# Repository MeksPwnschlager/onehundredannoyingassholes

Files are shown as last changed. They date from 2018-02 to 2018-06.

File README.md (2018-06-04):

# onehundredannoyingassholes 

Piezo Buzzer Throwies which buzz every 15-30 minutes and should last months.

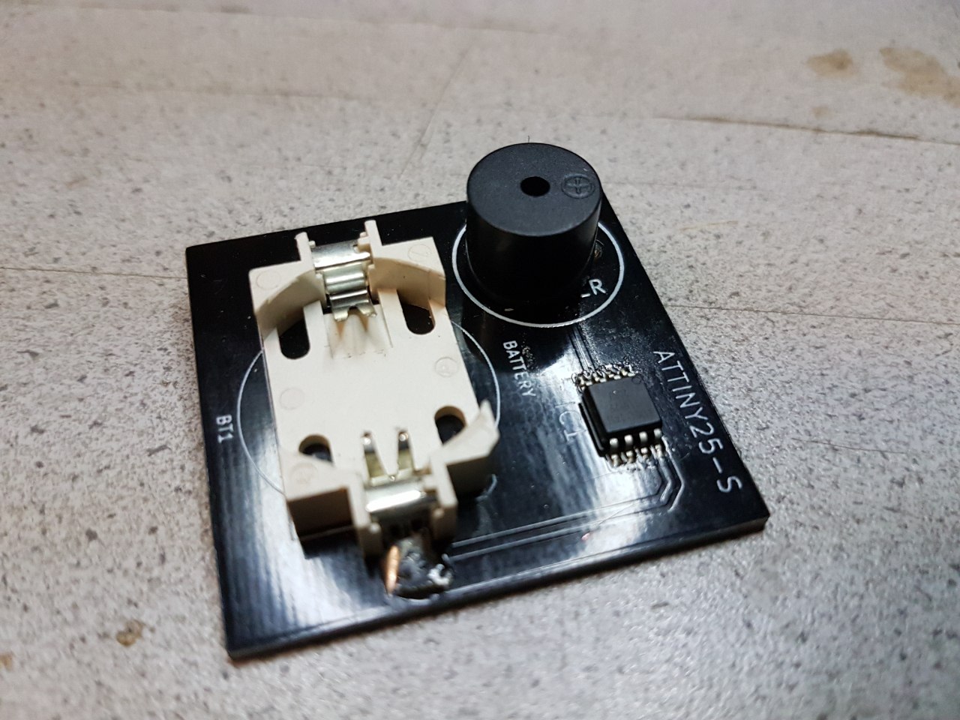
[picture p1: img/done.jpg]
Throwie


## Ingredients

 - ATTiny25 - 20SU
 - PCB (`kicad/`)
 - Piezo Buzzer
 - CRC2032 Battery
 - SMD CR2032 Battery Hodler
 - Code (`arduino/`)
 - SMD Solder Paste

1-1.50€/Piece

depending on what deals you get on the components.

## Making your own

### 1. Search for and buy the needed components at the electronics merchant of your choice.

For big orders `aliexpress.com` might be one of the cheaper options

### 2. Order the PCBs

We used `seeedstudio.com`, but `dirtypcbs.com` is also a cheap alternative. Maybe even buy a solder stencil to make your life easier!

### 3. Flash the chips

Use the included arduino code to flash the ATTiny25 using a POMONA Clip or other means of electrical contact and an AVR programmer.

### 4. Solder, Solder, Solder

Solder the SMD and normal compontents onto the board.

### 5. Annoy

Place the battery in the battery holder (duh) and listen to them beep!

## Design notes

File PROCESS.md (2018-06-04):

This is the story of how I made ~100 small, annoying and relatively cheap buzzer throwies. 

## The Idea

I actually didn't know something like this existed already until I looked it up. Although I could have expected it to, in light of human mischief.
I still didn't find a version I liked.

[This one](http://www.instructables.com/id/Buzzer-Throwie/) for example, is just a battery taped to a piezo speaker, which means it's active all the time and will be easily found.
A friend of mine apperently also built [something similar](https://chaosfield.at/projects/annoyotron.html), although it is not designed for "mass"-production. He even used an Attiny13 and wrote all the code directly in C, instead of using something like the Arduino IDE.
[The Annoy-O-Bug](https://www.hackster.io/AlexWulff/the-annoy-o-bug-a-chirping-light-up-throwie-37e58a) is a little different, it has a small mircocontroller and an LED. It uses the Attiny85. The undesired side-effect: One of theses costs almost 5 Euros.

I knew I had to make it more affordable, so I consulted with a few of my electronics-affine friends.
Our first instinct was to use two timers, one for the long intervals between beeps and one for the PWM for the piezo speaker.
Upon looking it up, we found that an Attiny25 was actually cheaper, so we went for that.

## The Prototype

[Overflo](https://github.com/overflo23), who owns [hackerspaceshop.com](https://hackerspaceshop.com) sent me a bunch of components to build a prototype. What an incredibly nice man!

It was like Christmas!

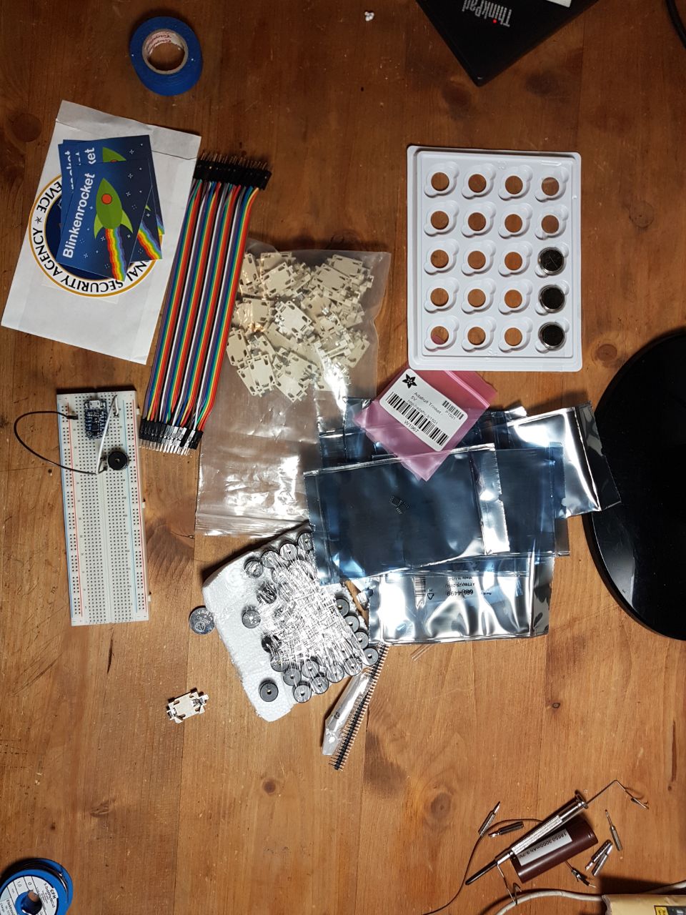
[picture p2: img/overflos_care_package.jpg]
It was like Christmas!


The first PCB was designed by [Amir](https://github.com/kallaballa) in a CAD program and home-made at our local hackerspace [Metalab](http://metalab.at).

We used spraypaint for the mask, which we removed with a LASER-Cutter where we wanted the copper to dissolve.

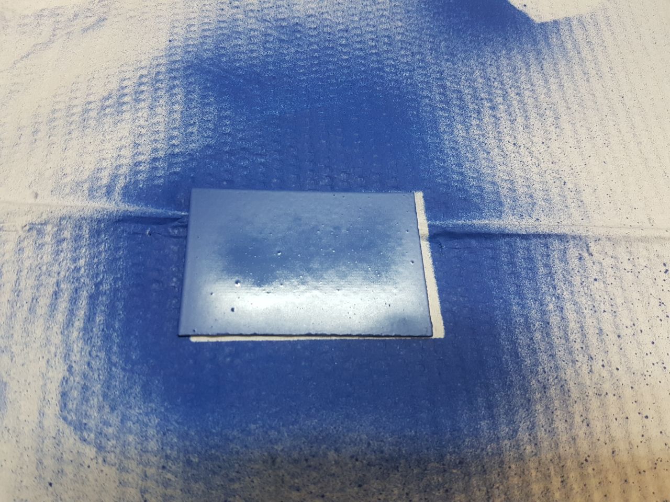
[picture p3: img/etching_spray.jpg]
Spray

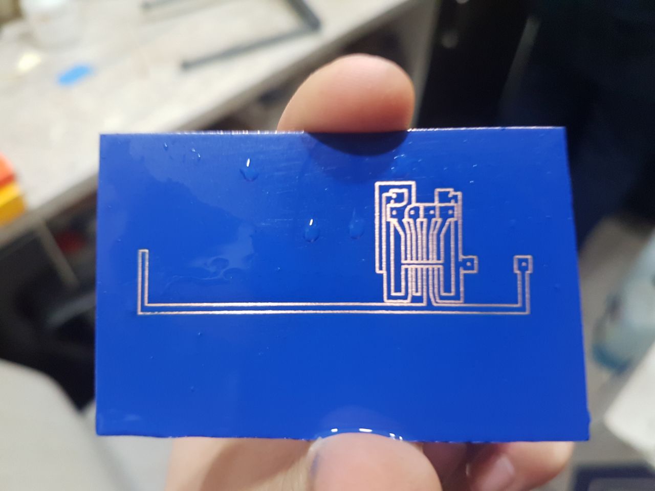
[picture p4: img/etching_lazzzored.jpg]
Lazzzored


Mixing the acid:

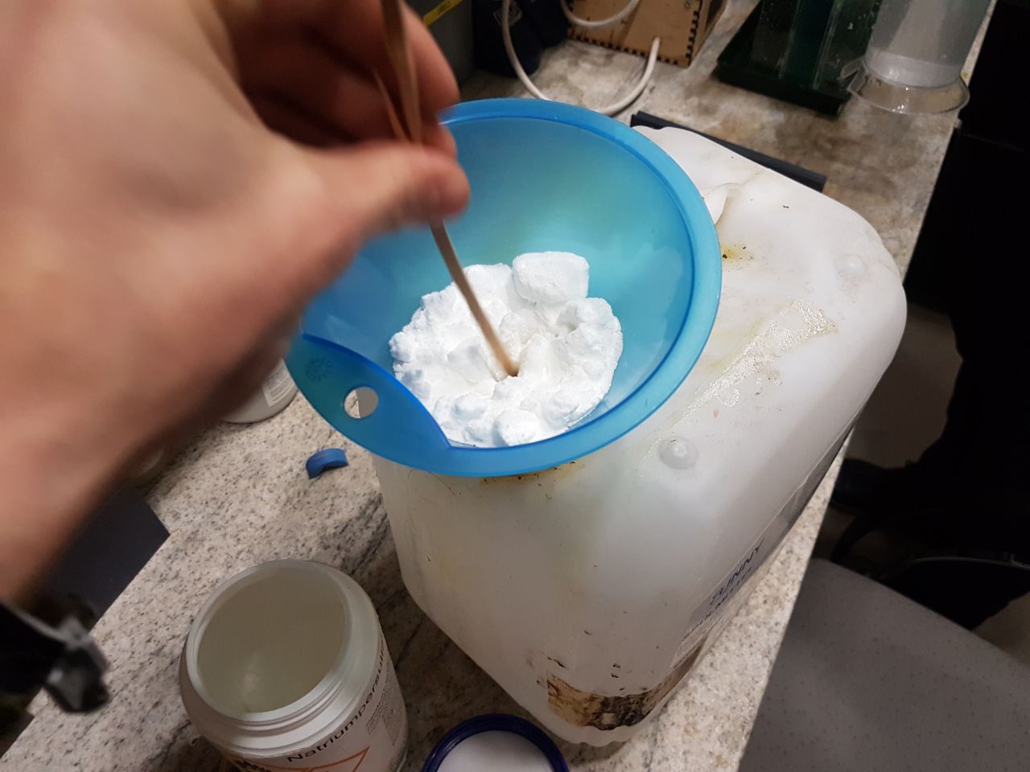
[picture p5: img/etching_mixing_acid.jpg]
Mixing


And in it goes!

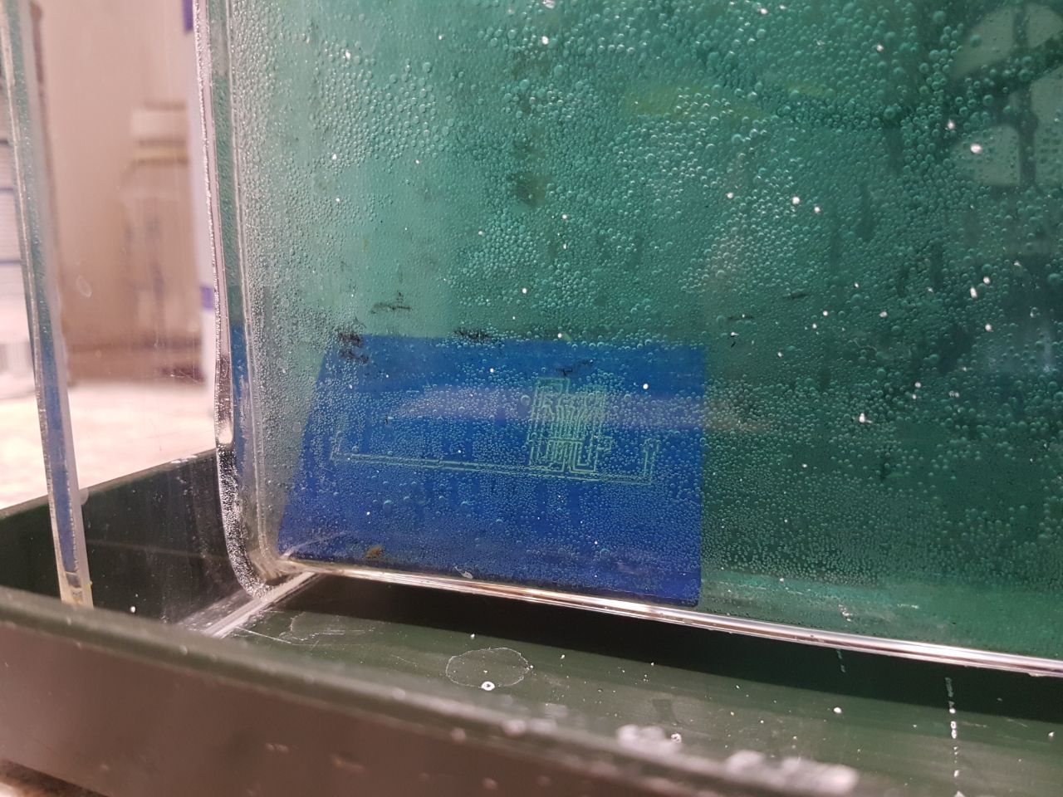
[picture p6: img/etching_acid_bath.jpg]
Nice Warm Bath


Metalab's heater for the acid bath was pretty broken, so we tried to build a new one:

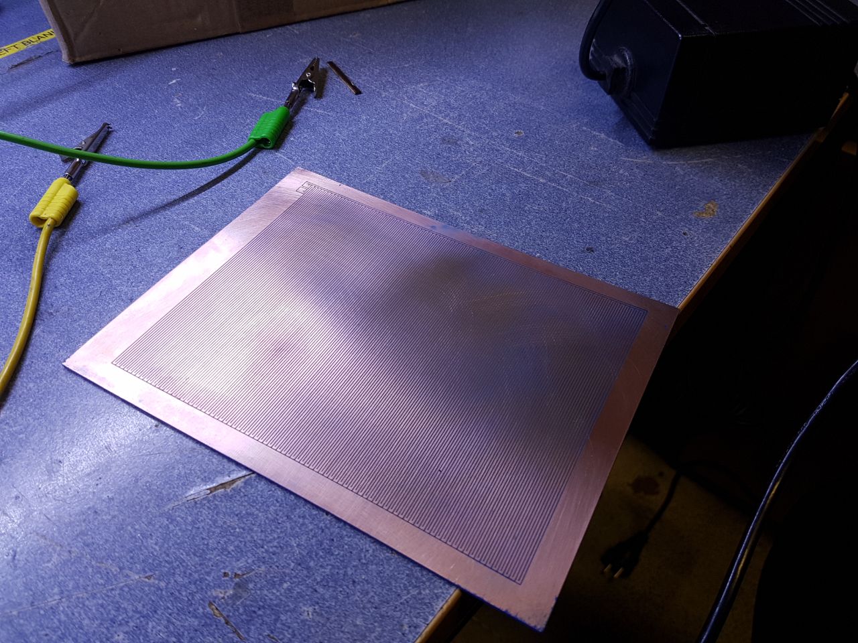
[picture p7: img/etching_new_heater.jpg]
New Heater


But that didn't work aswell, so I just sat there with a hot-air-gun to keep it from getting too chilly.

Needless to say, we noticed a mistake in the design right after it was done etching.
Thankfully this was easily fixable:

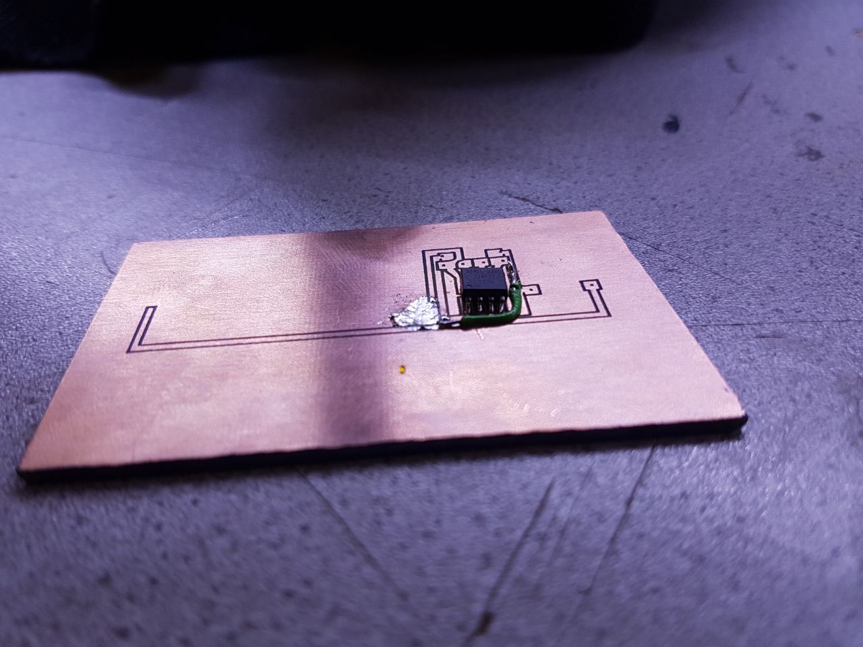
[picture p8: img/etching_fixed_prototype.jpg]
Easily fixable


We still wanted a proper PCB so we did it all again with a fixed design.

[This was the finished Prototype](https://www.youtube.com/watch?v=84bH-g-eUzU)

## Final Version 

[Vic](https://metalab.at/wiki/Benutzer:Vic) showed us around KiCAD and designed the final PCB for us! (The files in `kicad/`)

For the next step we had those made and bought all the other parts. Being multiple people, we were able to parallelise the work splitting it into: Flashing the Chips using a POMONA-Clip, applying the solder paste, baking the PCBs and hand soldering the components.

Enjoy this incrdibly compressed gif of the production process! (SMD Soldering, Peasant Soldering, etc.)

Production Process

Done!

A little later a few former school collegues and me distributed the throwies at our ex-school to wreak destruction, annoyance and havoc there! We even hot-glued magnets on some of the throwies to hide them in particularly evil places :D

Distribution

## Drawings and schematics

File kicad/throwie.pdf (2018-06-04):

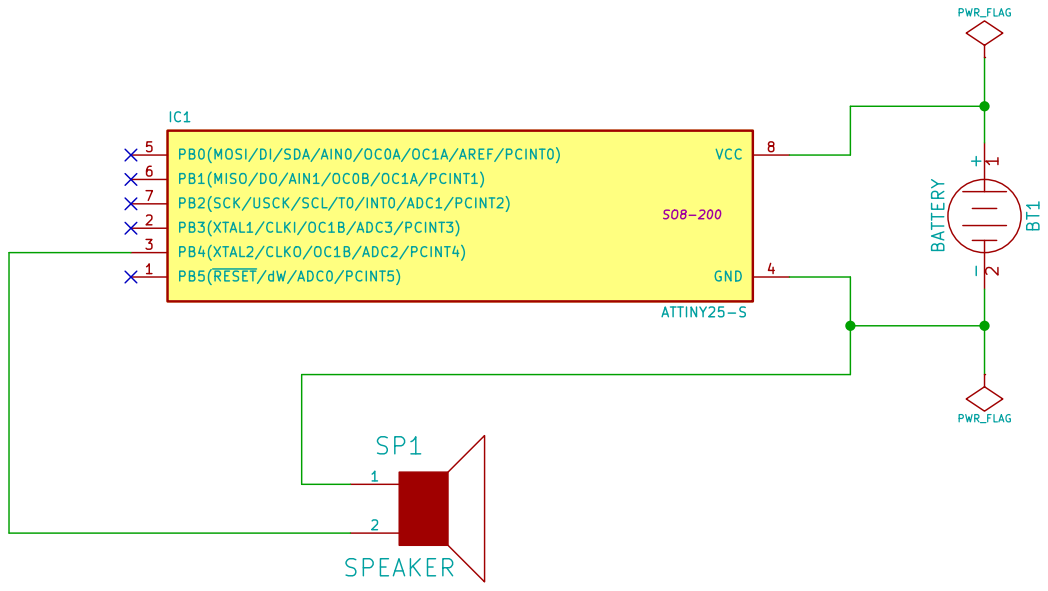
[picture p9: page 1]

SkunkWorks
Id: 1/1 Title: Throwie File: throwie.sch Sheet: /

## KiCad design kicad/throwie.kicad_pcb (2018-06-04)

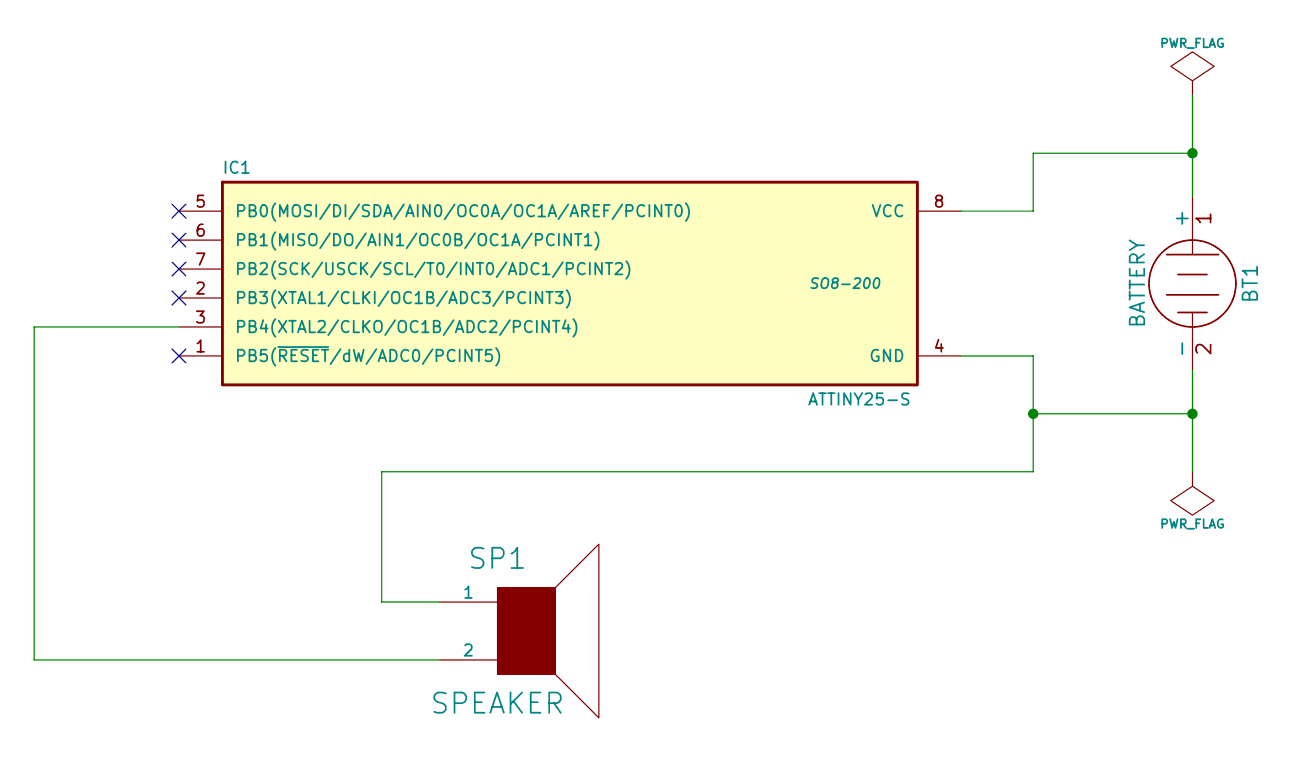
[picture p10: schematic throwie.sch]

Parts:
BT1: BATTERY
IC1: ATTINY25-S; SO8-200
SP1: SPEAKER

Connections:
unnamed: IC1.3 (PB4(XTAL2/CLKO/OC1B/ADC2/PCINT4)), SP1.2
unnamed: BT1.2 (-), IC1.4 (GND), SP1.1
unnamed: BT1.1 (+), IC1.8 (VCC)

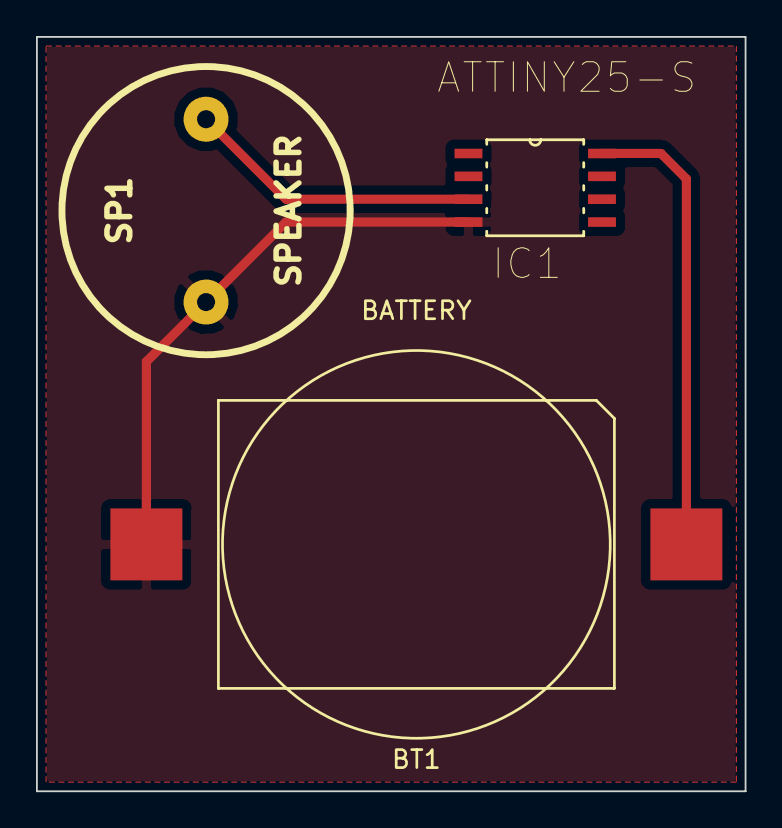
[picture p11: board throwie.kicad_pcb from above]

Board: 2 copper layers, 39.4 x 41.9 mm, 3 parts (0 on the bottom side), 3 nets.

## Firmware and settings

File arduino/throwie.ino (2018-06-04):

#include <avr/sleep.h>
#include <avr/power.h>
#include <avr/wdt.h>

int pin = 4;
int pitch = 0;
volatile boolean f_wdt=1;

void setup_watchdog(int ii) {   
  byte bb;  
  int ww; 
  if (ii > 9 )
    ii=9;
  bb=ii & 7; 
  if (ii > 7) 
    bb|= (1<<5); 
  bb|= (1<<WDCE);
  ww=bb;
  MCUSR &= ~(1<<WDRF); 
  // start timed sequence  
  WDTCR |= (1<<WDCE) | (1<<WDE);  // set new watchdog timeout value
  WDTCR = bb;
  WDTCR |= _BV(WDIE);
}

void setup() {
  randomSeed(analogRead(0));
  pinMode(pin, OUTPUT);
  ADCSRA &= ~(1<<ADEN); //Disable ADC, saves ~230uA
  setup_watchdog(9); //Setup watchdog to go off after 8sec
   for(uint8_t i = 0; i < 1 + random(4); ++i) {
    uint16_t pitch = 30 + random(200);
    long len = 50000 + random(100000);
    for(long j = 0; j < len; j+=pitch) {
    digitalWrite(pin, HIGH);
    delayMicroseconds(pitch);
    digitalWrite(pin, LOW);
    delayMicroseconds(pitch);
    }
  }
}

void sleep8sec() {
  set_sleep_mode(SLEEP_MODE_PWR_DOWN); // sleep mode is set here
  sleep_enable();
  sleep_mode(); //Go to sleep! Wake up 8sec later
}

void loop() {
  long ftmin = 100;
  
  //sleep ftmin * 8 seconds
  for(long i = 0; i < ftmin; ++i) {
    sleep8sec();
  }

  long interval = 1 + random(ftmin); 
  //sleep interval * 8 seconds
  for(long i = 0; i < interval; ++i) {
    sleep8sec();
  }
  
  for(uint8_t i = 0; i < 1 + random(4); ++i) {
    uint16_t pitch = 30 + random(200);
    long len = 50000 + random(100000);
    for(long j = 0; j < len; j+=pitch) {
    digitalWrite(pin, HIGH);
    delayMicroseconds(pitch);
    digitalWrite(pin, LOW);
    delayMicroseconds(pitch);
    }
  }
}

ISR(WDT_vect) {
  f_wdt=1;  // set global flag
}
